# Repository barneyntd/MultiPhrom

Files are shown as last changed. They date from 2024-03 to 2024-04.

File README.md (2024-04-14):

Multiphrom
==========

Multiphrom is a small microcontroller based board designed to emulate serial speech ROMS (phroms) for the BBC microcomputer.
It differs from many similar devices in several ways:
1.  Rather than emulating just one phrom, Multiphrom emulates up to 64;
2.  The contents of the emulated phroms can be updated at any time by inserting a micro-SD card;
3.  Multiphrom attempts to detect other phroms and stops using contended addresses;
4.  Multiphrom plugs into the official cartridge slot in the keyboard (the ashtray), or onto the external rom connector, PL14.

#### Project folders
- **kicad** This holds the schematic and pcb design, as a kicad project;
- **src** This holds the source code, written in C, and a Makefile to build it;
- **docs** This holds documents explaining how to use multiphrom, and the BBC micro speech system;
- **BASIC** This holds several sample programs, written in BBC BASIC.
- **Phroms** This holds some sample phroms for testing.

#### Licence
This project is licensed under creative commons licence [CC BY-NC-SA 4.0](https://creativecommons.org/licenses/by-nc-sa/4.0/).
This means that you are free to use it for any noncommercial purpose, provided you credit the copyright holder, and pass on the same conditions.
If you want to create a commercial product based on Multiphrom, you must obtain a seperate licence from the copyright holder.

The project includes the [sd-reader](http://www.roland-riegel.de/sd-reader/index.html) library by Roland Riegel, which is licenced under GNU LGPL v2.1.

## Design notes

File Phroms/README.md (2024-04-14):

Phroms
======

This folder contains sample phroms in the format used by MultiPhrom.
Put them on a micro-SD card, plug it into Multiphrom, and wait for the LED to go out.

> *I do not own the copyright on some of these files!
I have included them here for testing, but they should not be included in distributions.
If you are the copyright holder, please let me know what you would like me to do about your data*

1. **Ph\_EFR** This is VM71003A, the speaking clock rom.
2. **Ph\_F0R** This is VM61002, the phrom included in the US version of the model B.
3. **Ph\_FEN** This is a phrom created using PHSAVE, containing BASIC files for the \*ROM filing system.
4. **Ph\_FFN** This is CM62024, the Kenneth Kendal phrom included in the BBC speech upgrade.

The filename controls how MultiPhrom treats the files:
* Any filename not of the form "Ph\_hhr" where hh is a hex value between C0 and FF,
and r is N or R, is ignored.
* The two characters hh are the slot number in which the phrom will be installed.
Phrom data is not slot specific, so phroms can be installed in any slot.
* The character r controls whether the data will be bit-reversed. Rom dumps are usually
bit reversed; home created data is usually not.

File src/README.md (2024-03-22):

Building MultiPhrom
===================

This folder contains the source code for MultiPhrom's firmware. In order to build it, you will need:
1.  avr-gcc
2.  [avr-libc](https://github.com/avrdudes/avr-libc)   (if you use the atmega168pb mcu, you may need to edit some of the avr-libc files)
4.  [avrdude](https://github.com/avrdudes/avrdude)
5.  a suitable programmer.

Before building the firmware, you will probably need to edit the Makefile to suit your setup:
1.  You must set AVRDUDE_PROGRAMMER and AVRDUDE_PORT to whatever programmer you are using. See the avrdude documentation for details.
2.  The default microcontroller is an atmega168pb, but it should work with any atmega168 or atmega328 variant. Set MCU accordingly.

The board has a solder jumper marked "program". In order to protect the 3.3v memory chip from the 5v programming level, it is
advisable to desolder this jumper before programming, and resolder it after.

To build the firmware and program the mcu, connect up the programmer and execute the commands:
1.  `make setup`  (this is not needed if the mcu has been used before)
2.  `make clean`
3.  `make all`
4.  If you want to program several boards with the same firmware, you can use `make program`

If you get lots of errors about undefined things, you may need to edit the file `include/avr/io.h` in your avr-libc installation:
1.  After the line `#  include <avr/iom328p.h>` add the lines
     ```
    #elif defined (__AVR_ATmega328PB__)
    #  include <avr/iom328pb.h>
    ```
2.  After the line `#  include <avr/iom168pa.h>` add the lines
     ```
    #elif defined (__AVR_ATmega168PB__)
    #  include <avr/iom168pb.h>
    ```
3.  Make sure the files `include/avr/iom328pb.h` and `include/avr/iom168pb.h` exist

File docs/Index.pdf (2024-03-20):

CM62024 (BBC UK Phrom,

### Kenneth Kendall)

Index | Address | Word
32 | 0250 | (0.125)
33 | 35CA | TEN
34 | 0692 | 2- (TWEN-)
35 | 073F | 3- (THIR-)
36 | 07F7 | 4- (FOR-)
37 | 08B6 | 5- (FIF-)
38 | 0936 | 6- (SIX-)
39 | 09CB | 7- (SEVEN-)
40 | 0A46 | 8- (EIGHT-)
41 | 0AFD | 9- (NIN-)
42 | 3874 | TIME
43 | 2C45 | PLUS
44 | 0530 | THOUSAND (000)
45 | 2321 | MINUS
46 | 2C8B | POINT
47 | 2980 | ON
48 | 0437 | ZERO (0)
49 | 05CA | ONE,WON
50 | 0633 | TWO,TO,TOO
51 | 06D2 | THREE
52 | 0788 | FOUR,FOR,FORE
53 | 0840 | FIVE
54 | 08E9 | SIX
55 | 096E | SEVEN
56 | 0A12 | EIGHT,ATE
57 | 0A71 | NINE
58 | 0272 | (TONE 1)
59 | 02B0 | (TONE 2)
60 | 339A | SMALL
61 | 1F57 | IS
62 | 20FC | LARGE
63 | 3D1A | WHAT
64 | 0D46 | AMOUNT
65 | 0B5D | A
66 | 0065 | B,BEE,BE
67 | 124D | C,SEE,SEA
68 | 14F0 | D
69 | 175A | E
70 | 1A1C | F
71 | 1C6B | G
72 | 1D09 | H
73 | 1DCC | I,EYE
74 | 1FA6 | J,JAY
75 | 2008 | K
76 | 209F | L
77 | 226F | M
78 | 246F | N
79 | 27E5 | O
80 | 2A90 | P,PEA
81 | 2EC8 | Q,QUEUE
82 | 2F1E | R,ARE
83 | 31E1 | S
84 | 3573 | T,TEA,TEE
85 | 3A21 | U,YOU
86 | 3AF7 | V
87 | 3BB8 | W
88 | 3DB5 | X
89 | 3E11 | Y,WHY
90 | 3F9B | Z
91 | 341F | START
92 | 28D9 | OFF
93 | 349F | STOP
94 | 362B | THANK
95 | 21F5 | LINE
96 | 2D64 | POUN-
97 | 0E12 | AND
98 | 10BD | BAD
99 | 1483 | CORRECT
100 | 02E9 | -D
101 | 0300 | -ED
102 | 1AAB | FILE
103 | 1CC9 | GOOD
104 | 04C8 | HUNDRED (00)
105 | 1EBD | IN-
106 | 032B | -ING
107 | 2061 | KEY
108 | 1E3E | ILLEGAL
109 | 2409 | MUST
110 | 263D | NO,KNOW
111 | 29DE | ONLY
112 | 2DCD | PRESS
113 | 2892 | OF
114 | 3051 | RETURN
115 | 0361 | -S
116 | 36DF | THE
117 | 3F3D | YOUR
118 | 3B5C | VERY

VM61002 (BBC USA Phrom,

### American male)

Index | Address | Word
1 | 019E | ZERO
2 | 01EB | FOUR
3 | 0237 | EIGHT
4 | 026A | TWELVE
5 | 02B3 | TWENTY
6 | 02FF | ONE
7 | 0342 | FIVE
8 | 0395 | NINE
9 | 03ED | THIR-
10 | 0425 | HUNDRED
11 | 047C | TWO
12 | 04B3 | SIX
13 | 04E5 | TEN
14 | 051B | FIF-
15 | 0541 | THOUSAND
16 | 05BA | THREE
17 | 0606 | SEVEN
18 | 0650 | ELEVEN
19 | 06B8 | TEEN-
20 | 06EE | B
21 | 0720 | F
22 | 075A | J
23 | 079D | N
24 | 07DD | R
25 | 0809 | V
26 | 085D | ZEE
27 | 0899 | C
28 | 08DB | G
29 | 0919 | K
30 | 095A | O
31 | 0988 | S
32 | 09B8 | W
33 | 0A1E | D
34 | 0A52 | H
35 | 0A8D | L
36 | 0ACC | P
37 | 0B02 | T
38 | 0B3C | X
39 | 0B75 | A
40 | 0BA3 | E
41 | 0BD9 | I
42 | 0C1B | M
43 | 0C5A | Q
44 | 0C8E | U
45 | 0CCC | Y
46 | 0D0E | ALPHA
47 | 0D4F | ECHO
48 | 0D91 | DELTA
49 | 0DE4 | BRAVO
50 | 0E41 | FOXTROT
51 | 0EB0 | CHARLIE
52 | 0F01 | GOLF
53 | 0F39 | HENRY
54 | 0F89 | LIMA
55 | 0FD2 | PAPA
56 | 1014 | TANGO
57 | 106C | XRAY
58 | 10D0 | THE
59 | 10F7 | WATTS
60 | 1146 | METER
61 | 1191 | DANGER
62 | 11E4 | PRESSURE
63 | 1228 | CHANGE
64 | 1291 | MINUS
65 | 12E1 | NOT
66 | 1326 | START
67 | 1371 | LINE
68 | 13C5 | OFF
69 | 13F1 | TIME
70 | 142E | AUTOMATIC
71 | 14AC | WEIGHT
72 | 14FB | SMOKE
73 | 153C | ABORT
74 | 15A6 | CALL
75 | 15E2 | CYCLE
76 | 1630 | DISPLAY
77 | 168B | EQUAL
78 | 16DD | FAST
79 | 172B | ABOUT
80 | 1788 | GO
81 | 17AE | INCH
82 | 17F4 | LOW
83 | 1824 | MOTOR
84 | 1869 | OPEN
85 | 18B2 | PERCENT
86 | 1904 | PROBE
87 | 194E | READY

VM71003A (Time,

### American female)

Index | Address | Word
1 | 0048 | THE
2 | 006A | TIME
3 | 00F7 | IS
4 | 015C | A.M.
5 | 0203 | P.M.
6 | 0283 | OH
7 | 02BF | O-CLOCK
8 | 031D | ONE
9 | 0383 | TWO
10 | 03B6 | THREE
11 | 041E | FOUR
12 | 047B | FIVE
13 | 04F9 | SIX
14 | 052C | SEVEN
15 | 0584 | EIGHT
16 | 05CB | NINE
17 | 063F | TEN
18 | 06A6 | ELEVEN
19 | 0733 | TWELVE
20 | 07AE | THIRTEEN
21 | 084E | FOURTEEN
22 | 08C5 | FIFTEEN
23 | 0958 | SIXTEEN
24 | 09F0 | SEVENTEEN
25 | 0AAB | EIGHTEEN
26 | 0B46 | NINETEEN
27 | 0C08 | TWENTY
28 | 0C71 | THIRTY
29 | 0CDC | FOURTY
30 | 0D47 | FIFTY
31 | 0DA8 | GOOD-
32 | 0DC7 | MORNING
33 | 0E52 | AFTERNOON
34 | 0EF3 | EVENING
35 | 0F6C | (PAUSE)

VM61003 (Weather,

### American male)

Index | Address | Word
- | 0000 | ZERO
- | 004D | ONE
- | 0090 | TWO
- | 00C7 | THREE
- | 0113 | FOUR
- | 015D | FIVE
- | 0180 | SIX
- | 0203 | SEVEN
- | 0261 | EIGHT
- | 02A4 | NINE
- | 0336 | TEN
- | 0389 | ELEVEN
- | 0414 | TWELVE
- | 045D | THIRTEEN
- | 04E6 | FOURTEEN
- | 0584 | FIFTEEN
- | 060B | SIXTEEN
- | 0698 | SEVENTEEN
- | 073B | EIGHTEEN
- | 07AB | NINETEEN
- | 0845 | TWENTY
- | 0891 | THIRTY
- | 08E9 | FOURTY
- | 0956 | FIFTY
- | 09C1 | SIXTY
- | 0A2D | SEVENTY
- | 0AB0 | EIGHTY
- | 0B02 | NINETY
- | 0B6C | HUNDRED
- | 0BC3 | THOUSAND
- | 0C72 | MILLION
- | 0CEC | HALF
- | 0D4F | NEGATIVE
- | 0DE6 | POINT
- | 0E33 | AFFIRMATIVE
- | 0EE7 | TIMES
- | 0F69 | DIVIDED
- | 0FD9 | BY
- | 1047 | HOURS
- | 10AC | PLUS
- | 10F1 | MINUS
- | 116D | EQUALS
- | 11DB | RED
- | 1254 | YELLOW
- | 12A6 | GREEN
- | 1325 | WHITE
- | 136B | THE (EE)
- | 139E | THE (UH)
- | 13BF | ANSWER
- | 142A | IS
- | 1482 | START
- | 14E4 | STOP
- | 153D | READY
- | 157D | TEMPERATURE
- | 1610 | TIME
- | 167B | A.M.
- | 172D | P.M.
- | 17DF | O-CLOCK
- | 1847 | DEGREES
- | 18FE | CELCIUS
- | 19AC | FAHRENHEIT
- | 1A4B | ERROR
- | 1AA7 | MILES
- | 1B2F | PER
- | 1B74 | HOUR
- | 1BDB | MINUTES
- | 1C51 | GUSTING TO
- | 1D06 | DUST
- | 1D5E | EAST
- | 1DC4 | WEST
- | 1E30 | SOUTH
- | 1E91 | NORTH
- | 1EFE | NORTHEAST
- | 1FB7 | NORTHWEST
- | 2061 | SOUTHEAST
- | 210D | SOUTHWEST
- | 21C1 | HAIL
- | 222B | TORNADO
- | 22C2 | WIND
- | 2340 | WEATHER
- | 23BD | SHOWERS
- | 2448 | SLEET
- | 24AF | SMOKE
- | 2520 | STORM
- | 25AC | SNOW
- | 2627 | SAND
- | 26B6 | PELLETS

VM61004 (Military radio,

### American male)

Index | Address | Word
- | 0000 | ALPHA
- | 0064 | BRAVO
- | 00BC | CHARLIE
- | 011E | DELTA
- | 0171 | ECHO
- | 01B3 | FOXTROT
- | 0248 | GOLF
- | 0280 | HOTEL
- | 02F6 | INDIA
- | 0356 | JULIET
- | 03BC | KILO
- | 0409 | LIMA
- | 044C | MIKE
- | 048E | NOVEMBER
- | 052A | OSCAR
- | 0587 | PAPA
- | 05C9 | QUEBEC
- | 0610 | ROMEO
- | 0670 | SIERRA
- | 0706 | TANGO
- | 077D | UNIFORM
- | 07FB | VICTOR
- | 086E | WHISKY
- | 08C7 | XRAY
- | 093B | ZULU
- | 0984 | AFFIRMATIVE
- | 0A38 | NEGATIVE
- | 0ACF | MAYDAY
- | 0B74 | WARNING
- | 0C07 | ICING
- | 0C78 | DANGER
- | 0D0B | EMERGENCY
- | 0DD2 | ROGER
- | 0E50 | HERTZ
- | 0E8D | (PAUSE)
- | 0E96 | SECURITY
- | 0F13 | TARGET
- | 0F6E | VECTORS
- | 0FE6 | LIGHT
- | 103D | FRONT
- | 1098 | WAY
- | 10DA | GLIDE
- | 115E | OPEN
- | 11C2 | LIGHTS
- | 1221 | ON
- | 1287 | GUN DISH
- | 130A | ARDNAV
- | 13B9 | SELECT
- | 1420 | FILED
- | 14A5 | MIG
- | 1511 | ALERT
- | 1579 | ZONE
- | 15FD | TERMINAL
- | 167E | CANCEL
- | 16EB | RADIOS
- | 178E | SPEED
- | 1800 | KNOTS
- | 1868 | EXPECT
- | 18D6 | ACTION
- | 193C | RADIO
- | 19AA | POWER
- | 1A07 | PATH
- | 1A5F | INFORMATION
- | 1B09 | TRUE
- | 1B52 | PRESSURE
- | 1BBF | CHECK
- | 1BF6 | DECREASE
- | 1C63 | ADVISE
- | 1CED | YOU
- | 1D27 | HALF
- | 1D7E | ERROR
- | 1DDA | CALL
- | 1E31 | WRONG
- | 1E91 | NO
- | 1EEA | IMMEDIATELY
- | 1FA3 | FINAL
- | 200F | PLEASE
- | 205A | START
- | 20B6 | COURSE
- | 2102 | RADAR
- | 2181 | PLAN
- | 21EE | TARGET
- | 225B | WINDOWS
- | 22F3 | WATCH
- | 2336 | USE (S)
- | 2381 | TURN
- | 23CE | TRAFFIC

VM61005 (Aviation,

### American male)

Index | Address | Word
- | 0000 | A.P.U.
- | 00CC | F.S.S.
- | 01A8 | I.L.S.
- | 0276 | I.F.R.
- | 034B | V.F.R.
- | 0420 | V.H.E.
- | 052F | LANDING GEAR
- | 060C | LEVEL OFF
- | 06CE | UNDERCARRIAGE
- | 0791 | SPOILERS
- | 083F | AIR BRAKES
- | 08DB | AERIAL
- | 0960 | ENGINE
- | 09E4 | FLAMEOUT
- | 0A70 | FLAP LOAD
- | 0B36 | INBOUND
- | 0C08 | IGNITE
- | 0C7A | NO TURN
- | 0D47 | FLAPS
- | 0DB3 | EVACUATION
- | 0E8F | DOORS
- | 0F13 | CABIN
- | 0F7F | ARRIVAL
- | 1018 | AKNOWLEDGE
- | 10C2 | RAISE
- | 1156 | LIST
- | 11C2 | APPROACH
- | 123F | DEPARTURE
- | 12C5 | CLEARANCE DELIVERY
- | 13BB | FUEL
- | 142B | IDLE
- | 1495 | INCREASE
- | 150D | UP
- | 154E | TAXI
- | 15BB | EZZ
- | 15F6 | CONVERGING
- | 1690 | ABOVE
- | 16F6 | BRAKE
- | 174E | CALM
- | 17C6 | BRAKING
- | 1837 | CALL
- | 189E | CROSSWIND
- | 1938 | CRYSTALS
- | 19A6 | CYLINDER
- | 1A32 | CYCLE
- | 1A99 | DOWN
- | 1AF3 | GROUND
- | 1B4B | FULL
- | 1B9A | NEW
- | 1C19 | LEG
- | 1C8B | MAINTAIN
- | 1D37 | LANDING
- | 1DC2 | LEAN
- | 1E2E | SET
- | 1E75 | SHORT
- | 1ECB | WAKE
- | 1F28 | (PAUSE)
- | 1F31 | ATUS
- | 1F86 | NOTEM
- | 1FF9 | R.V.R.s
- | 20ED | SQUAWKING
- | 2161 | MAGNETOS
- | 220E | STABALISER
- | 22C7 | TACAN
- | 2344 | SELCAL
- | 23DF | VORTEC
- | 247F | V.O.R.
- | 256A | MARKER
- | 25DD | HEADING
- | 263E | E.T.A.
- | 26F4 | DOWNWIND
- | 2789 | CEILING
- | 27F2 | MIDPOINT
- | 288B | SIGMET
- | 2906 | ROLLOUT
- | 29A4 | PROPS
- | 29FD | AIRCRAFT
- | 2E89 | ALTIMETER
- | 2B20 | RUNWAY
- | 2BAB | AUTOPILOT
- | 2C47 | LOCALISER
- | 2CFE | COWL
- | 2D5D | IN FLIGHT
- | 2DF6 | OVER SPEED
- | 2EA7 | DEPARTURE
- | 2F3B | LAUNCH

119 | 3D6E | WHICH
120 | 276A | NUMBER
121 | 3EFC | YES
122 | 03DC | -Z
123 | 1B1E | FIRST
124 | 2A48 | OR
125 | 2195 | LAST
126 | 269D | NOT,KNOT
127 | 0250 | (0.125)
128 | 025F | (0.25)
129 | 0272 | (TONE 1)
130 | 02B0 | (TONE 2)
131 | 02E9 | -D
132 | 0300 | -ED
133 | 032B | -ING
134 | 0361 | -S
135 | 0384 | -TEE
136 | 03DC | -TH
137 | 03F3 | -T
138 | 0415 | -
139 | 0437 | ZERO (0)
140 | 04C8 | HUNDRED (00)
141 | 0530 | THOUSAND (000)
142 | 05CA | ONE,WON
143 | 0633 | TWO,TO,TOO
144 | 0692 | 2- (TWEN-)
145 | 06D2 | THREE
146 | 073F | 3- (THIR-)
147 | 0788 | FOUR,FOR,FORE
148 | 07F7 | 4- (FOR-)
149 | 0840 | FIVE
150 | 08B6 | 5- (FIF-)
151 | 08E9 | SIX
152 | 0936 | 6- (SIX-)
153 | 096E | SEVEN
154 | 09CB | 7- (SEVEN-)
155 | 0A12 | EIGHT,ATE
156 | 0A46 | 8- (EIGHT-)
157 | 0A71 | NINE
158 | 0AFD | 9- (NIN-)
159 | 0B5D | A
160 | 0BB6 | ACORN
161 | 0C4B | AFTER
162 | 0CB3 | AGAIN
163 | 0D46 | AMOUNT
164 | 0DBD | AN
165 | 0E12 | AND
166 | 0E8E | ANOTHER
167 | 0EFD | ANSWER
168 | 0F72 | ANY
169 | 0FCF | AVAILABLE
170 | 0065 | B,BEE,BE
171 | 10BD | BAD
172 | 013B | BETWEEN
173 | 01B1 | BOTH
174 | 01F8 | BUTTON
175 | 124D | C,SEE,SEA
176 | 12B1 | CASSETTE
177 | 1326 | CHARACTER
178 | 139F | COMPLETE
179 | 140B | COMPUTER
180 | 1483 | CORRECT
181 | 14F0 | D
182 | 153B | DATA
183 | 159F | DATE
184 | 15E6 | DO
185 | 162A | DOLLAR
186 | 167E | DONT
187 | 16D7 | DOWN
188 | 175A | E
189 | 178B | EACH
190 | 17D6 | ELEVEN
191 | 1852 | ENGAGED
192 | 18FA | ENTER
193 | 195C | ERROR
194 | 19AA | ESCAPE
195 | 1A1C | F
196 | 1A5D | FEW
197 | 1AAB | FILE
198 | 1B1E | FIRST
199 | 1896 | FOUND
200 | 1C11 | FROM
201 | 1C6B | G
202 | 1CC9 | GOOD
203 | 1D09 | H
204 | 1D60 | HAVE
205 | 1DCC | I,EYE
206 | 1E3E | ILLEGAL
207 | 1EBD | IN-
Index | Address | Word
88 | 198E | SET
89 | 19CC | SPEED
90 | 1A16 | UNDER
91 | 1A6A | OPERATOR
92 | 1AE7 | INDIA
93 | 1B3B | MIKE
94 | 1B7D | QUEBEC
95 | 1BC4 | UNIFORM
96 | 1C42 | YANKEE
97 | 1CA5 | AMPS
98 | 1CE0 | MEGA
99 | 1D2A | PICO
100 | 1D80 | FIRE
101 | 1DD3 | POWER
102 | 1E21 | COMPLETE
103 | 1E8B | REPAIR
104 | 1EEC | TEMPERATURE
105 | 1F41 | STOP
106 | 1F70 | MACHINE
107 | 1FCE | ON
108 | 200A | CONTROL
109 | 2071 | ELECTRICIAN
110 | 20E2 | AT
111 | 2111 | RED
112 | 2160 | ALL
113 | 2197 | CANCEL
114 | 21DD | PHASE
115 | 221F | NOR
116 | 226C | EXIT
117 | 22BA | FLOW
118 | 22FB | GAUGE
119 | 234A | GREEN
120 | 23B9 | INSPECTOR
121 | 242A | MANUAL
122 | 24A1 | MOVE
123 | 24FC | OVER
124 | 2547 | PLUS
125 | 2583 | PULL
126 | 25BD | REPEAT
127 | 2621 | SHUT
128 | 2658 | TEST
129 | 2696 | VOLTS
130 | 26D3 | GALLONS
131 | 2737 | JULIET
132 | 279D | NOVEMBER
133 | 2814 | ROMEO
134 | 2874 | VICTOR
135 | 28CB | ZULU
136 | 2914 | HERTZ
137 | 2948 | MICRO
138 | 299C | OHMS
139 | 29F0 | AREA
140 | 2A43 | CIRCUIT
141 | 2A9E | CONNECT
142 | 2AEB | SECONDS
143 | 2B55 | UNIT
144 | 2BB2 | TIMER
145 | 2BFD | UP
146 | 2C28 | IS
147 | 2C5F | ALERT
148 | 2CBA | ADJUST
149 | 2D1B | BETWEEN
150 | 2D77 | MINUTES
151 | 2DBD | BUTTON
152 | 2E0B | CLOCK
153 | 2E49 | DEVICE
154 | 2E97 | EAST
155 | 2ED8 | FAIL
156 | 2F1D | FREQUENCY
157 | 2F8B | GATE
158 | 2FD4 | HIGH
159 | 300A | INTRUDER
160 | 307D | MEASURE
161 | 30CE | NORTH
162 | 3121 | PASS
163 | 3172 | POSITION
164 | 31D1 | PUSH
165 | 3201 | WRITE
166 | 324A | SLOW
167 | 3292 | TOOL
168 | 32D1 | WEST
169 | 3324 | KILO
170 | 3373 | OSCAR
171 | 33C6 | SIERRA
172 | 341D | WHISKY
173 | 3476 | AND
174 | 34CD | FARAD
175 | 351D | MILLI
176 | 3556 | CAUTION
Index | Address | Word
- | 2718 | RAIN
- | 2788 | ICE
- | 27E6 | FEET
- | 282E | FOG
- | 289D | HEAVY
- | 28DF | LAND
- | 294F | IN
- | 298F | ON
- | 29CB | VARIABLE
- | 2A6A | OBSCURED
- | 2B09 | BROKEN
- | 2B68 | ALOFT
- | 2BDF | CEILING
- | 2C48 | PARTIALLY
- | 2CC2 | VISIBILITY
- | 2D7A | DRIZZLE
- | 2DDD | INDICATED
- | 2E74 | SEVERE
- | 2ED7 | MODERATE
- | 2F59 | GREENWICH
- | 2FCA | MEAN
- | 3043 | MIST
- | 30C0 | ESTIMATED
- | 314D | DECREASING
- | 31F0 | MOVING
- | 325C | PRESSURE
- | 32C9 | ALTERNATE
- | 334F | CLEAR
- | 33AA | CURRENT
- | 33F4 | FLOWING
- | 3470 | AT
- | 34AA | TURBULENCE
- | 353B | THINLY
- | 3599 | INCREASING
- | 3634 | MORE THAN
- | 36DB | LESS THAN
- | 3763 | FREEZING
- | 37EA | AIR
- | 382A | BELOW
- | 38A6 | AND
- | 38ED | FOR
- | 3927 | HAZE
- | 39A5 | HIGH
- | 3A0D | SCATTERED
- | 3A8E | INCREASING TO
- | 3B6A | IN
- | 3BB7 | LOW (SHORT)
- | 3BE7 | OF
- | 3C2E | (PAUSE)
- | 3C37 | THUNDERSTORMS
- | 3CFB | OVERCAST
- | 3DC7 | UNLIMITED
- | 3E7B | LOW (LONG)
- | 3EF4 | PERCENT
- | 3F46 | OVER
Index | Address | Word
- | 2435 | TECH
- | 248A | SLOW
- | 24F9 | RELEASE
- | 256D | KEY
- | 25A8 | IGNITION
- | 2639 | DEGREE
- | 26A4 | GRAIN
- | 26F9 | REPAIR
- | 277C | CANCEL
- | 2806 | VERIFY
- | 28A0 | READY
- | 28FA | USE (Z)
- | 2976 | OUT
- | 29BF | OTHER
- | 2A25 | OIL
- | 2A78 | OFF
- | 2AC6 | MIRROR
- | 2B26 | RATE
- | 2B93 | MIXTURE
- | 2C16 | MUCH
- | 2C6E | RATE
- | 2CD0 | IS
- | 2D28 | CAUTION
- | 2D97 | BELOW
- | 2E13 | CYLINDER
- | 2E90 | CONTACT
- | 2F0A | AND
- | 2F51 | FUEL
- | 2FA8 | FOR
- | 2FE2 | SEQUENCE
- | 3068 | SIDE
- | 30C3 | SLOW
- | 3119 | TO
- | 3148 | RICH
- | 31B6 | PUMPS
- | 320C | LEVEL
- | 3273 | LOWER
- | 32E5 | REAR
- | 3364 | HOLD
- | 33C9 | LONG
- | 3435 | LEVEL
- | 34AE | LEFT
- | 350F | RIGHT
- | 356F | OPEN
- | 35C9 | STRAY
- | 3659 | CLOSED
- | 36E2 | EVACUATE
- | 379A | FAILURE
- | 3807 | SERVICE
- | 3881 | ABORT
- | 3902 | IDENTIFY
- | 3999 | TOO LOW
- | 3A2F | CENTRE
- | 3AA9 | AREA
- | 3B09 | BASE
- | 3B45 | CONTROL
- | 3BBB | MEASURED
- | 3C41 | THE (EE)
- | 3C74 | THE (UH)
- | 3C95 | VACUUM
- | 3D13 | ABEAM
- | 3D95 | (PAUSE)
Index | Address | Word
- | 2F9F | TOWER
- | 3006 | FLIGHT WATCH
- | 30AC | STALL
- | 312B | TOUCHDOWN
- | 31BF | SQUAWK
- | 321D | ELEVATION
- | 32D0 | CLIMB
- | 3342 | BANK
- | 33A3 | ACCELERATED
- | 344E | TRIM
- | 34A0 | UNICOM
- | 3546 | SLOPE
- | 3595 | NINER
- | 361E | GALLEY
- | 3675 | FREEDOM
- | 36F0 | FLIGHT
- | 3749 | DEGREE
- | 37B4 | AIRPORT
- | 3820 | AIR SPEED
- | 38AE | CLEARENCE
- | 3920 | ALTITUDE
- | 39BB | RADIO
- | 3A53 | REMARK
- | 3AEA | REFUELLING
- | 3B9C | OUTER
- | 3BF9 | MIDDLE
- | 3C5F | INNER
- | 3CAC | INSTRUMENTS
- | 3D55 | FLIGHT
- | 3DB0 | APPROACHES
- | 3E55 | GEAR
- | 3EA8 | BOOST
- | 3EE7 | TELEPHONE
Index | Address | Word

208 | 1EFC | INPUT
209 | 1F57 | IS
210 | 1FA6 | J,JAY
211 | 2008 | K
212 | 2061 | KEY
213 | 209F | L
214 | 20FC | LARGE
215 | 2195 | LAST
216 | 21F5 | LINE
217 | 226F | M
218 | 22CD | MANY
219 | 2321 | MINUS
220 | 239D | MORE
221 | 2409 | MUST
222 | 246F | N
223 | 24C9 | NAME
224 | 2544 | NEGATIVE
225 | 25DE | NEW
226 | 263D | NO,KNOW
227 | 269D | NOT,KNOT
228 | 26F7 | NOW
229 | 276A | NUMBER
230 | 27E5 | O
231 | 282D | O'CLOCK
232 | 2892 | OF
233 | 28D9 | OFF
234 | 2923 | OLD
235 | 2980 | ON
236 | 29DE | ONLY
237 | 2A48 | OR
238 | 2A90 | P,PEA
239 | 2AC7 | PARAMETER
240 | 2B58 | PENCE
241 | 2BBA | PLEASE
242 | 2C45 | PLUS
243 | 2C8B | POINT
244 | 2CE6 | POSITIVE
245 | 2D64 | POUN-
246 | 2DCD | PRESS
247 | 2E3F | PROGRAM
248 | 2EC8 | Q,QUEUE
249 | 2F1E | R,ARE
250 | 2F59 | RED
251 | 2FD1 | RESET
252 | 3051 | RETURN
253 | 30E7 | RUN
254 | 3153 | RUNNING
255 | 31E1 | S
256 | 3231 | SAME
257 | 329A | SCORE
258 | 3320 | SECOND
259 | 339A | SMALL
260 | 341F | START
261 | 349F | STOP
262 | 34FB | SWITCH
263 | 3573 | T,TEA,TEE
264 | 35CA | TEN
265 | 362B | THANK
266 | 3684 | THAT
267 | 36DF | THE
268 | 3724 | THEN
269 | 377E | THIRD
270 | 3808 | THIS
271 | 3874 | TIME
272 | 3800 | TRY
273 | 3953 | TWELVE
274 | 39D2 | TYPE
275 | 3A21 | U,YOU
276 | 3A91 | UH
277 | 3AC0 | UP
278 | 3AF7 | V
279 | 3B5C | VERY
280 | 3BB8 | W
281 | 3C1D | WANT
282 | 3C6C | WAS
283 | 3CC2 | WERE
284 | 3D1A | WHAT
285 | 3D6E | WHICH
286 | 3DB5 | X
287 | 3E11 | Y,WHY
288 | 3E86 | YEAR
289 | 3EFC | YES
290 | 3F3D | YOUR
291 | 3F9B | Z
Index | Address | Word
177 | 35B1 | LIGHT
178 | 3601 | CHECK
179 | 3635 | DEGREES
180 | 36CB | SERVICE
181 | 3721 | SWITCH
182 | 376E | VALVE
183 | 37CC | VAL
184 | 3820 | NUMBER
185 | 3880 | OUT
186 | 38B5 | POINT
187 | 3904 | BREAK
188 | 3948 | HOURS
189 | 39AD | CALIBRATE
190 | 3A21 | CRANE
191 | 3A75 | DIRECTION
192 | 3AE3 | ENTER
193 | 3B17 | FEET
194 | 3B56 | FROM
195 | 3B86 | GAP
196 | 3BC8 | HOLD
197 | 3C22 | LEFT
198 | 3C61 | MILL
199 | 3C9C | OF
200 | 3CC5 | PAST
201 | 3D11 | PRESS
202 | 3D54 | RANGE
203 | 3DB2 | SAFE
204 | 3DF2 | SOUTH
205 | 3E48 | TURN
206 | 3E8B | YELLOW
Index | Address | Word

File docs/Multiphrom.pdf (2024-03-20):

# Multiphrom

Multiphrom is a serial rom emulator for use with the TMS5220 speech chip, designed to get the most possible out of the BBC micro speech system. This document summarises what I have learnt about the speech system, and describes how to use Multiphrom.

## Phrom Numbers

The Speech System User Guide implies that the system can access up to 16 phroms, numbered 0–F, each holding 16Ki of data. In fact, both the TMS5220 and OS1.2 use a 20 bit address, accessing up to 64 phroms; the limitation is the TMS6100 serial rom, which ignores the top two bits. Multiphrom uses all 20 bits, emulating 64 phroms numbered -64 to -1 or &FFC0 to &FFFF. If you use a genuine TMS6100 chip it will appear four times, as &Cn, &Dn, &En, and &Fn.

## Phrom Formats

There are three data formats used in TMS6100 roms for the Beeb, and rom dumps are found in both bit orders. I will refer to the order used in the Speech System User Guide (which puts the Acorn copyright message in the Kenneth Kendal rom into Ascii) as Normal order, and the opposite as Reversed order, and I will describe all data in Normal order. Note that most pointers are reversed, but most other data is not.

### Acorn Format

This is the format described in the Speech System User Guide, and used in the Kenneth Kendal rom (CM62024). The rom starts with a 64 byte header which is completely ignored by the speech system (though used by the *ROM filing system), then continues exactly as Indexed Format. In fact, if you use word numbers less than 32, OS1.2 will interpret the header as part of the index and produce random noise.

### Indexed Format

This is the format used in the US phrom (VM61002), and the speaking clock phrom (VM71003A). In practice, this is the format assumed by OS1.2 for speech data, since it is identical to Acorn format for word numbers greater than 31. To speak words in this format, use

### SOUND ph, wn, 0, 0

where ph is the phrom number (&FFC0–&FFFF) and wn the word number.

Address | Data
0 | 00
1 | word count reversed (not checked by OS1.2)
2 | word 1 address low byte reversed
3 | word 1 address high byte reversed
⋮
2n | word n address low byte reversed
2n+1 | word n address high byte reversed

The rest of the phrom is speech data exactly like Unformatted phroms.

### Unformatted Phroms

This is the format used by the other three easily available phroms (VM61003, VM61004, VM61005) and is just raw data, starting at address zero, one word starting at the first byte after another ends. To speak words in this format, use

### SOUND ph-&40, wadd, 0, 0

where ph-&40 is the phrom number minus 64 (&FF80–&FFBF) and wadd the address of the start of the word (relative to the start of the phrom).
The data is a sequence of frames which can be 4, 11, 19, or 50 bits long, packed into bytes from high bit to low bit, and byte aligned only at word boundaries. Each frame is a sequence of up to twelve parameters, each of 3,4,5 or 6 bits, which index standard tables. I believe each parameter is in Normal order, but I haven’t checked this.

## Loading Phroms into Multiphrom

You can load any phrom into any slot in multiphrom. Create a file containing the raw binary data at the root level of a micro-SD card, with the name Ph_XXN if the bytes are in normal order, or Ph_XXR if they are reversed, where XX is the slot you want to put it in (C0-FF). Insert the card into multiphrom and the led will light; when it goes out you can remove the card and use the speech system. Each slot takes about 5 seconds to load, so it is a good idea to delete or rename phrom files after loading.
If you have a genuine TMS6100 installed, it will take up four slots. Multiphrom should detect it and disable itself for those slots, but I haven’t been able to test this properly, as I don’t have a TMS6100. You can still load data into those slots, but not use it until you remove the TMS6100.

## Using the *ROM Filing System

In OS1.2, the *ROM FS only searches slots &F0–&FF, so capacity is limited to 256KiB including overheads. It would be a simple patch (I believe only one byte) to allow all 64 slots for 1MiB storage; if any original cartridges exist they would then be repeated four times in the catalogue, which doesn’t seem much of a downside. The format is as described in the New Advanced User Guide, all in normal order, with a header as described in the Speech System Users Guide with pointers in reversed order. I have written a BASIC program to generate appropriate phrom files, but files running over more than one slot should be considered beta, as there is no good documentation, and I haven’t had time to test it thoroughly.

## The Board, V2.0

The board contains an Atmega 168pb micro-controller, an AT25SF081 flash rom, a micro-SD card socket, and various components to connect them together. It is designed to plug into the cartridge socket to the left of the keyboard (the “ashtray”) on a BBC micro. If you don’t have a socket fitted in your Beeb, I recommend buying a 30 pin edge connector (Amp 5530843-2) and pulling out all the contacts on the left hand side, and the third, fourth and fifth from the top on the right, then put a key in the third position. This can be done with fine nosed pliers, and the socket will then solder to the keyboard PCB. WARNING: you may need fix PCB errors on either the main board or the keyboard; check the instructions in the BBC service manual for details. Failure to fix these errors may fry the board.

The board can also be plugged into PL14 (the second keyboard connector) on the Beeb either with a female header connector or a cable but WARNING: the pins are not quite in the same order. The -5V line is shifted from one end to the other, and connecting this wrong may fry the board. The simplest solution is to connect only the other nine lines, since -5V is not used by the board. If you decide to do this, do check the schematics carefully!

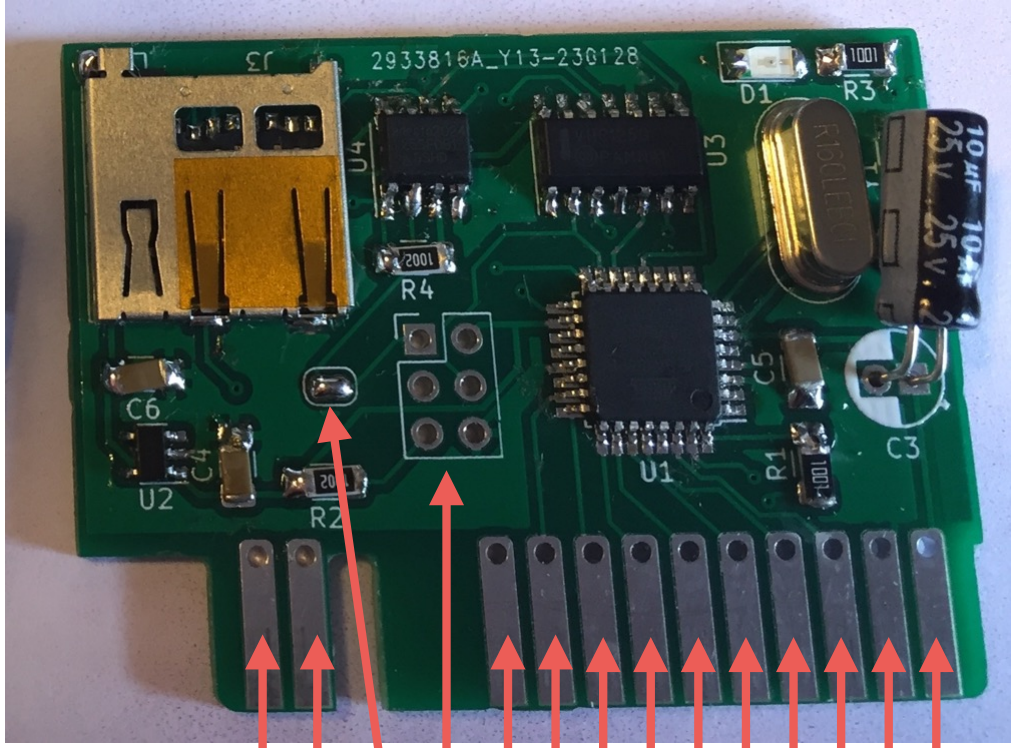
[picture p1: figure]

After testing, the flash rom should contain the UK speech phrom in slot FF, the US speech phrom in slot F0, the US speaking clock phrom in slot EF, and some BASIC programs (in *ROM format) in slot FE.

If you ever want to update the firmware, first desolder the programming jumper with desoldering braid, to protect the 3.3V chips from the 5V programming signals. The programming connector is a standard (Arduino style) ISP6 connector, and any Atmel-compatible programmer should work. After programming, remember to resolder the programming jumper.

## Questions for Beta Testers

- Does it work reliably? Can you use it in all the expected ways?
- Can you find interesting new ways to use it? Are there straightforward improvements I could make to make it more useful?
- How easy is it to install in a Beeb? Which connection system works best?
- (If you have a genuine TMS6100) Does the automatic detection of genuine phroms work? You can test this with SOUND -17 for the UK phrom, or -32 for the US phrom: if the detection works, this should produce the installed phrom, just like SOUND -1 or -16. If it doesn’t, I recommend
removing the TMS6100 when using Multiphrom. NC | NC | Programming jumper | Programming connector | -5V ⁽NC⁾
A1

A2

A4

A8

RCLCK
M0

M1

0V

+5V

## The Programs

I’ve included some simple programs which use the speech rom, in case you find them useful. These are installed in slot FE (using PHSAVE) so you can load them using *ROM. Feel free to use or adapt them in any way you like.

### PHDUMP

PHDUMP generates a hex dump of the contents of any phrom slot. Just input the slot number in hex, and it will print out the contents, formatted for 80 column modes. For 40 column modes, change the 16 in line 200 to 8 (or however many bytes per line you prefer).

input slot number, and ensure it’s meaningful:
10 PRINT"Input slot number (C0-FF)"; 20 INPUT SN$
30 SN=EVAL("&"+SN$) AND &3F
100 @%=4

set bottom twelve bits of speech address to zero: 110 *FX 159,0,64
120 *FX 159,0,64
130 *FX 159,0,64

set top six bits of address to slot, and next two to zero:
140 A%=159:X%=0:Y%=64+SN*4 MOD 16:R%=USR(&FFF4) 150 A%=159:X%=0:Y%=64+SN DIV 4:R%=USR(&FFF4)

loop through entire phrom slot:
160 FOR I%=0 TO &3FFF

tell TMS5220 to read byte:
170 *FX 159,0,16

read byte from phrom:
180 A%=158:R%=USR(&FFF4)
190 Y%=((R% DIV &10000)-1) AND &FF

print newline & address every 16 bytes, then read byte:
200 IF I% MOD 16 = 0 THEN PRINT:PRINT~I%," ",; 210 PRINT ~Y%,;

loop & end
220 NEXT
230 END

### PHLIST

PHLIST searches through all installed phroms looking for those in Acorn format, recognised by the copyright message which starts at byte 2. This is useful to find which slots contain *ROM files.

loop through the 64 slots:
100 FOR PN%=0 TO 63

set the bottom 14 address bits to &0002 and the top six to the slot number: 110 *FX 159,0,66
120 *FX 159,0,64

130 *FX 159,0,64
140 A%=159:X%=0:Y%=64+PN%*4 MOD 16:CALL(&FFF4)
150 A%=159:X%=0:Y%=64+PN% DIV 4:CALL(&FFF4)

if the next three characters are not “(C)” go on to the next slot:
160 IF FNREADBYTE <> &28 OR FNREADBYTE <> &43 OR FNREADBYTE <> &29 THEN NEXT:END

read the copyright and title strings, and print them out:
170 C$="(C)"+FNREADSTRING
180 T$=FNREADSTRING
190 PRINT ~PN%+&C0;": ";T$;" “;C$

go on to next slot:
200 NEXT:END

function to read a byte at the current address: 210 DEF FNREADBYTE
220 *FX 159,0,16
230 A%=158:R%=USR(&FFF4)
240 = ((R% DIV &10000)-1) AND &FF

function to read a 0-terminated string at the current address: 250 DEF FNREADSTRING
260 R$=""
270 REPEAT:C=FNREADBYTE
280 IF C=0 THEN UNTIL TRUE: =R$ 290 R$=R$+CHR$(C)
300 UNTIL FALSE

### PHINDEX

PHINDEX searches through an unindexed phrom to find the start address of words. You need the address of the first word; it then scans through, assuming each word immediately follows the last. This technique allowed me to generate indexes of all the readily available TI roms.
Input the slot number (in hex) of the phrom you want to index, then the start address (in hex) of the first word (usually 0); it will then print the address and speak the word, before prompting “More?”. You can press return to continue the search, type a new address, or type N to stop.

input slot number & start address, and make meaningful:
100 INPUT"Slot number (C0-FF)",SN$
110 SN=EVAL("&"+SN$) AND &3F
120 INPUT"Start address (Hex)",SA$
130 SA=EVAL("&"+SA$) MOD &4000

keep track of how many bits are read:
135 BIT%=0
140 REPEAT
150 PRINT "Trying “;~SA

speak the next word (if it is one) & confirm to continue the search:
160 SOUND&FF80+SN,SA,0,0
170 INPUT "More",Q$:IF LEFT$(Q$,1)="N" THEN END
175 IF Q$<>"" THEN SA=EVAL("&"+Q$) MOD&4000:UNTIL FALSE set the 20-bit speech address:
180 A%=159:X%=0:Y%=&40+(SA AND &0F):CALL(&FFF4)
190 A%=159:X%=0:Y%=&40+(SA DIV &10 AND &0F):CALL(&FFF4)
200 A%=159:X%=0:Y%=&40+(SA DIV &100 AND &0F):CALL(&FFF4)
210 A%=159:X%=0:Y%=&40+(SN*4+SA DIV &1000 AND &0F):CALL(&FFF4) 220 A%=159:X%=0:Y%=&40+SN DIV 4:CALL(&FFF4)

loop through the word just spoken:
240 REPEAT

energy is four bits; get more if necessary:
250 IF BIT%<4 THEN PROCNextByte
260 BIT%=BIT%-4:Energy = BYTE% DIV 2^BIT%:BYTE% = BYTE% MOD 2^BIT%

energy 0 means pause, no other data needed:
270 IF Energy=0 THEN UNTIL FALSE

energy 15 means end of word:
280 IF Energy=15 THEN UNTIL TRUE:SA=SA+1:UNTIL FALSE

repeat is one bit, pitch is six bits; if repeat, no more is needed:
290 IF BIT%<1 THEN PROCNextByte
300 BIT%=BIT%-1:Repeat = BYTE% DIV 2^BIT%:BYTE% = BYTE% MOD 2^BIT% 310 IF BIT%<6 THEN PROCNextByte
320 BIT%=BIT%-6:Pitch = BYTE% DIV 2^BIT%:BYTE% = BYTE% MOD 2^BIT% 330 IF Repeat=1 THEN UNTIL FALSE

K1 to K4 are 18 bits total; if pitch is 0 no more is needed:
340 PROCNextByte:PROCNextByte:IF BIT%<18 THEN PROCNextByte
350 BIT%=BIT%-18:K1234 = BYTE% DIV 2^BIT%:BYTE% = BYTE% MOD 2^BIT% 360 IF Pitch=0 THEN UNTIL FALSE

K5 to K10 are 21 bits total:
370 PROCNextByte:PROCNextByte:IF BIT%<21 THEN PROCNextByte
380 BIT%=BIT%-21:K5to10 = BYTE% DIV 2^BIT%:BYTE% = BYTE% MOD 2^BIT%

loop & end:
390 UNTIL FALSE
990 END

read the next byte from the speech processor:
1000 DEF PROCNextByte
1010 *FX 159,0,16
1020 A%=158:R%=USR(&FFF4):B%=((R% DIV &10000)-1) AND &FF 1030 BYTE%=BYTE%*&100+B%:BIT%=BIT%+8
1035 SA=SA+1
1040 ENDPROC

### PHSAVE

PHSAVE creates a phrom file in *ROM format, which is useful to store programs which you can then access without any sideways-rom based filing system. The file is saved in the current filing system, so you need to use some other method to copy it to the root of a micro-SD card before loading it into Multiphrom.

OS1.2 only reads files from slots F0–FF, so it will warn you if you use slots C0–EF. The slot is only used to generate the filename, so you can move to a different slot simply by renaming the file. At the prompt, enter a filename to be read from the current filesystem and added to the rom, or a *command, which can be used to change directory (I’m not sure if changing filesystem will work), or #title, which creates an empty file to use as a catalog separator. When you have done all the files you want, press return at the prompt to complete the phrom file. This version does support files which run over into the next phrom (and changes the filename accordingly), but OS 1.2 gives Block? errors when you *CAT them, unless you turn on *OPT 1,2.

reserve space for OSFILE & OSGBPB operations, and define machine code routines:
1000 DIM BUFF% 260:DIM CTRL% 18:X%=CTRL% AND &FF:Y%=CTRL% DIV &100 1010 PROCCODE(BUFF%)

input slot number & ensure it’s ok:
1020 REPEAT
1030 PRINT "Enter Phrom slot number (C0-FF)";:INPUT PHFN$ 1040 PHFN = EVAL("&"+PHFN$)
1050 UNTIL PHFN >= &C0 AND PHFN <= &FF
1060 IF PHFN < &F0 THEN PRINT "Warning: OS 1.2 only reads files from slots F0 - FF”

open the file for saving the created phrom:
1070 PROCOPEN

loop for each file saved:
1080 REPEAT
1090 PRINT "Slot " STR$~PHFN ", " &3FFF-EXT#(PHFILE) " bytes free." 1100 PRINT "Enter filename to save in Phrom, or *command, or #title,":PRINT "or RETURN to finish";
1110 INPUT SFN$

if blank, end; if * pass to OSCLI; if # create empty file:
1120 IF SFN$ = "" THEN UNTIL TRUE:PROCCLOSE:END
1130 IF LEFT$(SFN$,1) = "*" THEN OSCLI MID$(SFN$,2):UNTIL FALSE 1140 IF LEFT$(SFN$,1)="#"THEN PROCTITLE(MID$(SFN$,2)):UNTIL FALSE

call OSFILE to read file info:
1150 !CTRL%=BUFF%:$BUFF%=SFN$
1160 A%=5:R%=USR(&FFDD)
1170 IF (R% AND &FF) <> 1 THEN PRINT "File not found.":UNTIL FALSE

L% is the length of the file, BLKS% is the number of 256-byte blocks, LA% is the load address, EA% the execution address, AT% the file attributes, SSFN$ the filename simplified for *ROM: 1180 L%=CTRL%!10:BLKS%=(L%-1) DIV 256 +1
1190 LA%=CTRL%!2:EA%=CTRL%!6:AT%=CTRL%?14
1200 SSFN$=SFN$:REPEAT:SSFN$=MID$(SSFN$,INSTR(SSFN$,".")+1):UNTIL INSTR(SSFN$,".")=0
1210 SSFN$=LEFT$(SSFN$,10):N%=LEN(SSFN$)

calculate the address of the next file (or end of rom marker) in NXT%:
1220 NXT%=FNNXT(0)

open the file to be saved, and loop through the blocks:
1230 SFILE=OPENIN(SFN$)
1240 FOR I%=1 TO BLKS%

if we’ve reached the end of the rom, close the rom file and open a new one, recalculating the address of the next file:
1250 FLAG% = (PTR#PHFILE = NXT%):IF FLAG% THEN PROCCLOSE: PHFN=PHFN+1: PROCOPEN: NXT%=FNNXT(I%-1)

if this is the first or last block of a file, or first block of a rom, write a full header, otherwise &23: 1260 IF FLAG% OR I%=1 OR I%=BLKS% THEN PROCHEADER(I%=BLKS%,EOF#(SFILE),I%-1) ELSE BPUT#PHFILE,&23

read a block from the input file, calculate the CRC, and write both to the output file
1270 ?CTRL%=SFILE:CTRL%!1=BUFF%:CTRL%!5=256
1280 A%=4:R%=USR(&FFD1)
1290 BL%=CTRL%!1-BUFF%:!(CTRL%!1)=FNCRC(BL%)
1300 ?CTRL%=PHFILE:CTRL%!1=BUFF%:CTRL%!5=BL%+2 1310 A%=2:R%=USR(&FFD1)

loop, close the rom file and end:
1320 NEXT
1330 CLOSE#SFILE
1340 UNTIL FALSE
1350 END

calculate the next free address in the rom; if it’s past the end reduce until it fits: 1360 DEF FNNXT(DONE%)
1370 LOCAL BASE%,FULL%
1380 BASE%=PTR#PHFILE+N%+20
1390 IF BASE% > &3FFE THEN = PTR#PHFILE
1400 FULL%=BASE%+L%+BLKS%*3-DONE%*259:IF BLKS%-DONE% > 1 THEN FULL%=FULL%+N%+20
1410 IF FULL% <= &3FFE THEN = FULL% ELSE = BASE%+((&3FFE - BASE%) DIV 259) * 259

close the rom file, first writing &2B at the end, and the end address in the header:
1420 DEF PROCCLOSE
1430 BPUT#PHFILE,&2B
1440 PTR#PHFILE=60:BPUT#PHFILE,FNREVBYTE(EXT#PHFILE AND &FF):BPUT#PHFILE,FNREVBYTE(EXT#PHFILE DIV &100)
1450 CLOSE#(PHFILE)
1460 ENDPROC

open the rom file and write the (minimal) rom header:
1470 DEF PROCOPEN
1480 LOCAL I%
1490 PHFILE = OPENOUT("Ph_"+STR$~(PHFN)+"N")
1500 BPUT#PHFILE,0:BPUT#PHFILE,0:BPUT#PHFILE,ASC(“("): BPUT#PHFILE,ASC("C"):BPUT#PHFILE,ASC(")")
1510 FOR I%=1TO48:BPUT#PHFILE,32:NEXT
1520 BPUT#PHFILE,0:BPUT#PHFILE,0:BPUT#PHFILE,0:BPUT#PHFILE,0: BPUT#PHFILE,0:BPUT#PHFILE,0:BPUT#PHFILE,0:BPUT#PHFILE,&FF:BPUT#PHFI LE,&FF:BPUT#PHFILE,2:BPUT#PHFILE,0
1530 ENDPROC

write the full file header:
1540 DEF PROCHEADER(LAST%,EMPTY%,BN%) 1550 LOCAL I%
1560 $BUFF%=SSFN$

1570 BUFF%?N%=0:BUFF%!(N%+1)=LA%:BUFF%!(N%+5)=EA%:BUFF%!(N%+9)=BN% 1580 IF LAST% THEN BUFF%!(N%+11)=L% - PTR#SFILE:BUFF%?(N%+13)=&80 ELSE BUFF%!(N%+11)=256:BUFF%?(N%+13)=0
1590 IF EMPTY% THEN BUFF%?(N%+13)=BUFF%?(N%+13) OR &40
1600 IF AT% AND 4 THEN BUFF%?(N%+13)=BUFF%?(N%+13) OR 1
1610 BUFF%!(N%+14)=NXT%:BUFF%!(N%+18)=FNCRC(N%+18)
1620 BPUT#PHFILE,&2A:FOR I%=0 TO N%+19:BPUT#PHFILE,BUFF%?I%:NEXT 1630 ENDPROC

write an empty file:
1640 DEF PROCTITLE(N$)
1650 SSFN$=LEFT$(N$,10):N%=LEN(SSFN$)
1660 LA%=0:EA%=0:AT%=0:L%=0
1665 IF PTR#PHFILE >= &3FFE-N%-20 THEN PROCCLOSE: PHFN=(PHFN+1)AND&FF:PROCOPEN
1670 NXT%=PTR#PHFILE+N%+21
1680 PROCHEADER(TRUE,TRUE,0)
1690 ENDPROC

call the machine code CRC routine:
1700 DEF FNCRC (A%)
1710 R%=USR(CRC)
1720 =!&81

call the machine code byte reverse: 1730 DEF FNREVBYTE (A%)
1740 R%=USR(REVERSE)
1750 =R% MOD 256

assemble the two machine code routines: 1760 DEF PROCCODE(BUFF%)
1770 DIM MC% 100
1780 FOR I=0 TO 2 STEP 2
1790 P% = MC%
1800 [OPTI
1810 .REVERSE STA &80
1820 ROL &80
1830 ROR A
1840 ROL &80
1850 ROR A
1860 ROL &80
1870 ROR A
1880 ROL &80
1890 ROR A
1900 ROL &80
1910 ROR A
1920 ROL &80
1930 ROR A
1940 ROL &80
1950 ROR A
1960 ROL &80
1970 ROR A
1980 RTS
1990 .CRC STA &80
2000 LDA #0
2010 STA &82

2020 STA &81
2030 TAY
2040 .NBYT LDA &81
2050 EOR BUFF%,Y
2060 STA &81
2070 LDX #8
2080 .LOOP LDA &81
2090 ROL A
2100 BCC B7Z
2110 LDA &81
2120 EOR #8
2130 STA &81
2140 LDA &82
2150 EOR #&10
2160 STA &82
2170 .B7Z ROL &82
2180 ROL &81
2190 DEX
2200 BNE LOOP
2210 INY
2220 CPY &80
2230 BNE NBYT
2240 RTS
2250 ]
2260 NEXT
2270 ENDPROC

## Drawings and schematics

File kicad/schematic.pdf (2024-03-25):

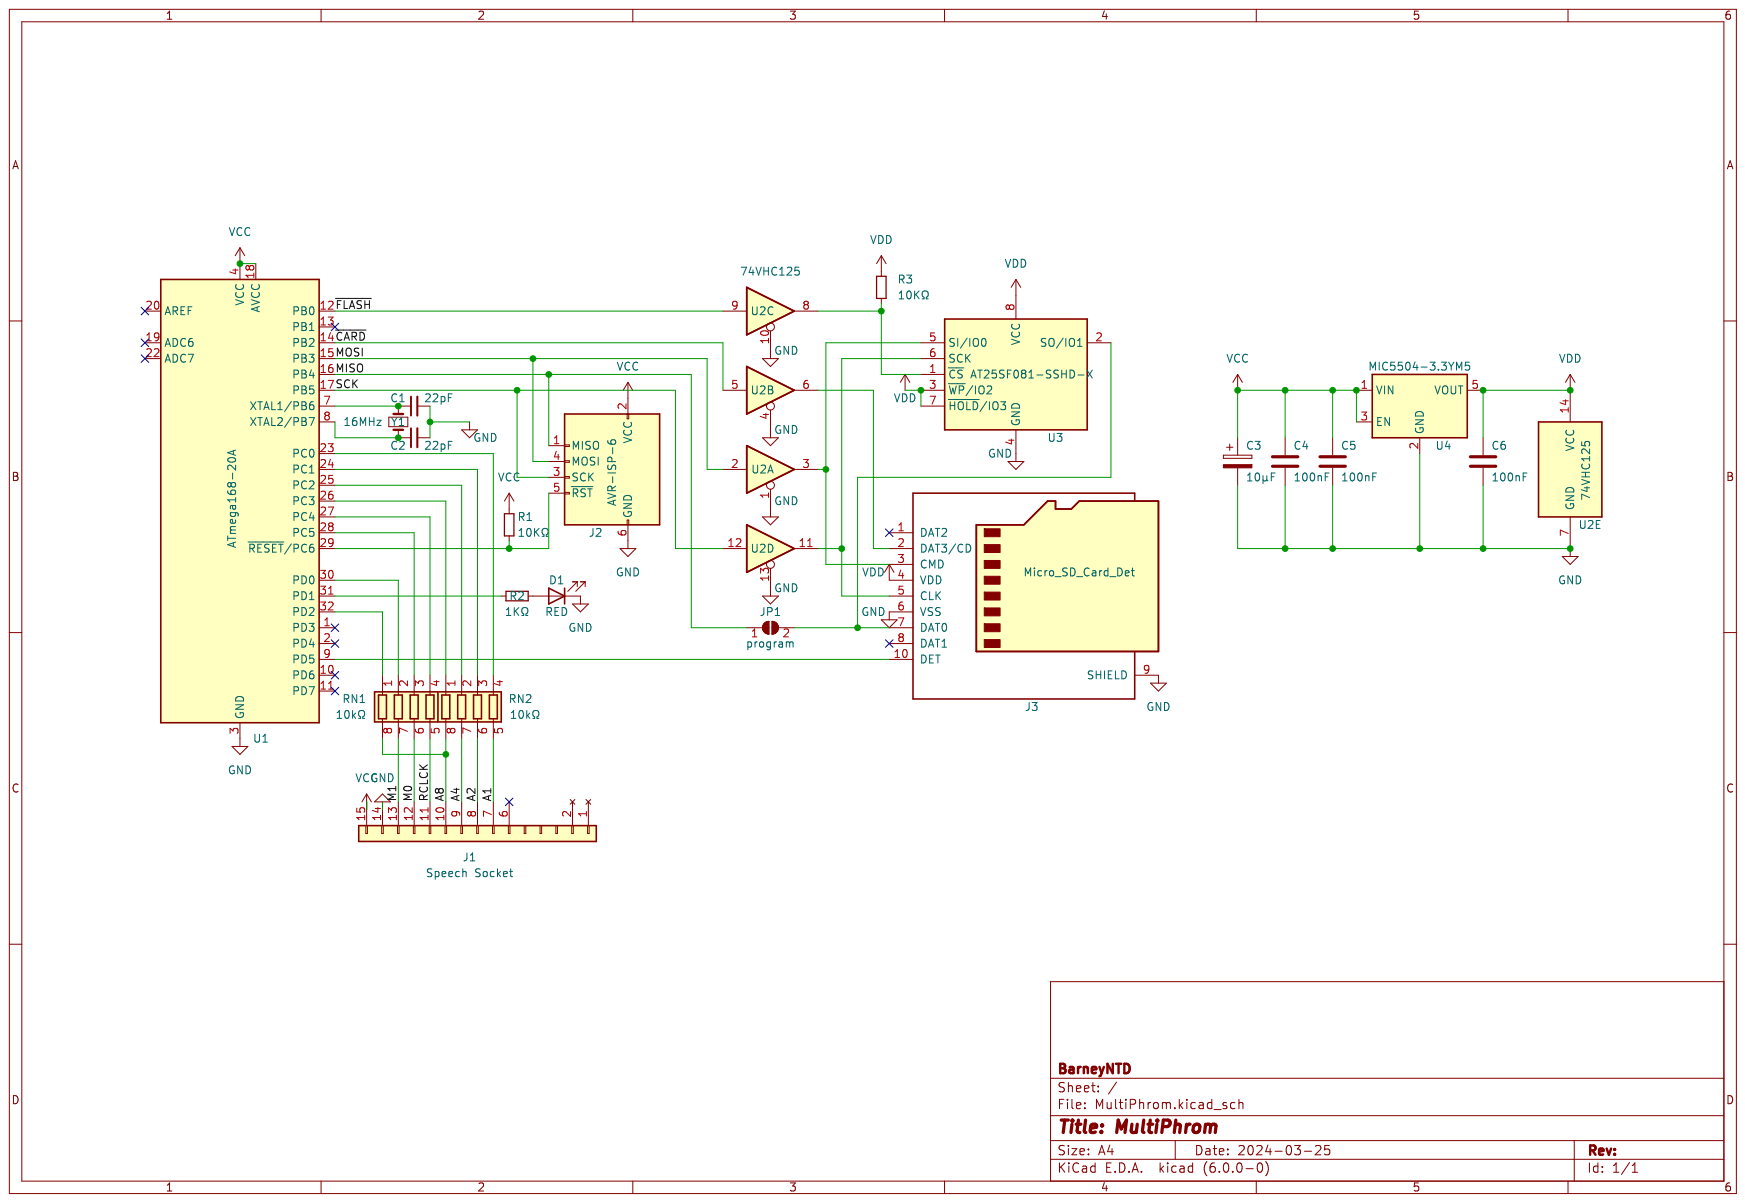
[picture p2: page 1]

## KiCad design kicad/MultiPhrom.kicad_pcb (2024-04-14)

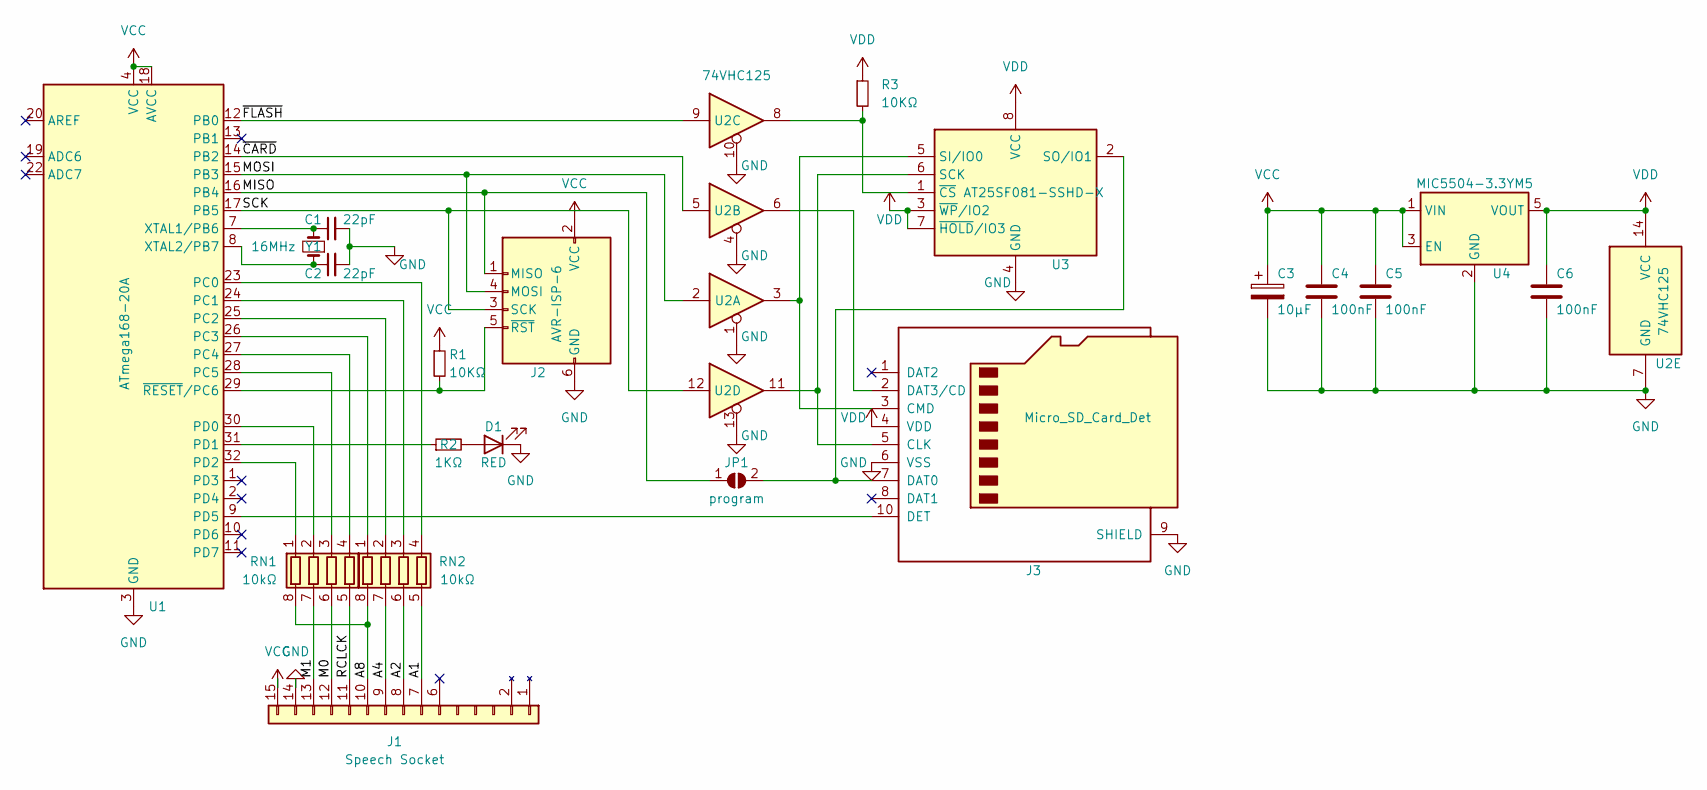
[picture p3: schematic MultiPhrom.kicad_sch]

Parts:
C1, C2: 22pF; C_1206_3216Metric_Pad1.33x1.80mm_HandSolder
C3: 10µF; CP_Radial_D5.0mm_P2.00mm
C4, C5, C6: 100nF; C_1206_3216Metric_Pad1.33x1.80mm_HandSolder
D1: RED; LED_1206_3216Metric_Pad1.42x1.75mm_HandSolder
J1: Speech Socket; BBC Speech Socket
J2: AVR-ISP-6; PinHeader_2x03_P2.54mm_Vertical
J3: Micro_SD_Card_Det; WR-CRD 693071010811
JP1: program; SolderJumper-2_P1.3mm_Open_RoundedPad1.0x1.5mm
R1, R3: 10KΩ; R_1206_3216Metric_Pad1.30x1.75mm_HandSolder
R2: 1KΩ; R_1206_3216Metric_Pad1.30x1.75mm_HandSolder
RN1, RN2: 10kΩ; R_Array_Convex_4x1206
U1: ATmega168-20A; TQFP-32_7x7mm_P0.8mm
U2: 74VHC125; SO-14_3.9x8.65mm_P1.27mm
U3: AT25SF081-SSHD-X; SOIC-8_3.9x4.9mm_P1.27mm
U4: MIC5504-3.3YM5; SOT-23-5
Y1: 16MHz; Crystal_HC49-4H_Vertical

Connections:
/A1: J1.7, RN2.5 (R4.2)
/A2: J1.8, RN2.6 (R3.2)
/A4: J1.9, RN2.7 (R2.2)
/A8: J1.10, RN1.8 (R1.2), RN2.8 (R1.2)
/M0: J1.12, RN1.6 (R3.2)
/M1: J1.13, RN1.7 (R2.2)
/MISO: J2.1 (MISO), JP1.1 (A), U1.16 (PB4)
/MOSI: J2.4 (MOSI), U1.15 (PB3), U2.2
/RCLCK: J1.11, RN1.5 (R4.2)
/SCK: J2.3 (SCK), U1.17 (PB5), U2.12
/~CARD: U1.14 (PB2), U2.5
/~FLASH: U1.12 (PB0), U2.9
GND: C1.2, C2.2, C3.2, C4.2, C5.2, C6.2, D1.1 (K), J1.14, J2.6 (GND), J3.6 (VSS), J3.9 (SHIELD), U1.3 (GND), U1.5 (GND), U1.21 (GND), U2.1, U2.4, U2.7 (GND), U2.10, U2.13, U3.4 (GND), U4.2 (GND)
unnamed: C1.1, U1.7 (XTAL1/PB6), Y1.2
unnamed: C2.1, U1.8 (XTAL2/PB7), Y1.1
unnamed: D1.2 (A), R2.2
unnamed: J2.5 (~RST), R1.2, U1.29 (~RESET/PC6)
unnamed: J3.2 (DAT3/CD), U2.6
unnamed: J3.3 (CMD), U2.3, U3.5 (SI/IO0)
unnamed: J3.5 (CLK), U2.11, U3.6 (SCK)
unnamed: J3.7 (DAT0), JP1.2 (B), U3.2 (SO/IO1)
unnamed: J3.10 (DET), U1.9 (PD5)
unnamed: R2.1, U1.31 (PD1)
unnamed: R3.2, U2.8, U3.1 (~CS)
unnamed: RN1.1 (R1.1), U1.32 (PD2)
unnamed: RN1.2 (R2.1), U1.30 (PD0)
unnamed: RN1.3 (R3.1), U1.28 (PC5)
unnamed: RN1.4 (R4.1), U1.27 (PC4)
unnamed: RN2.1 (R1.1), U1.26 (PC3)
unnamed: RN2.2 (R2.1), U1.25 (PC2)
unnamed: RN2.3 (R3.1), U1.24 (PC1)
unnamed: RN2.4 (R4.1), U1.23 (PC0)
VCC: C3.1, C4.1, C5.1, J1.15, J2.2 (VCC), R1.1, U1.4 (VCC), U1.6 (VCC), U1.18 (AVCC), U4.1 (VIN), U4.3 (EN)
VDD: C6.1, J3.4 (VDD), R3.1, U2.14 (VCC), U3.3 (~WP/IO2), U3.7 (~HOLD/IO3), U3.8 (VCC), U4.5 (VOUT)

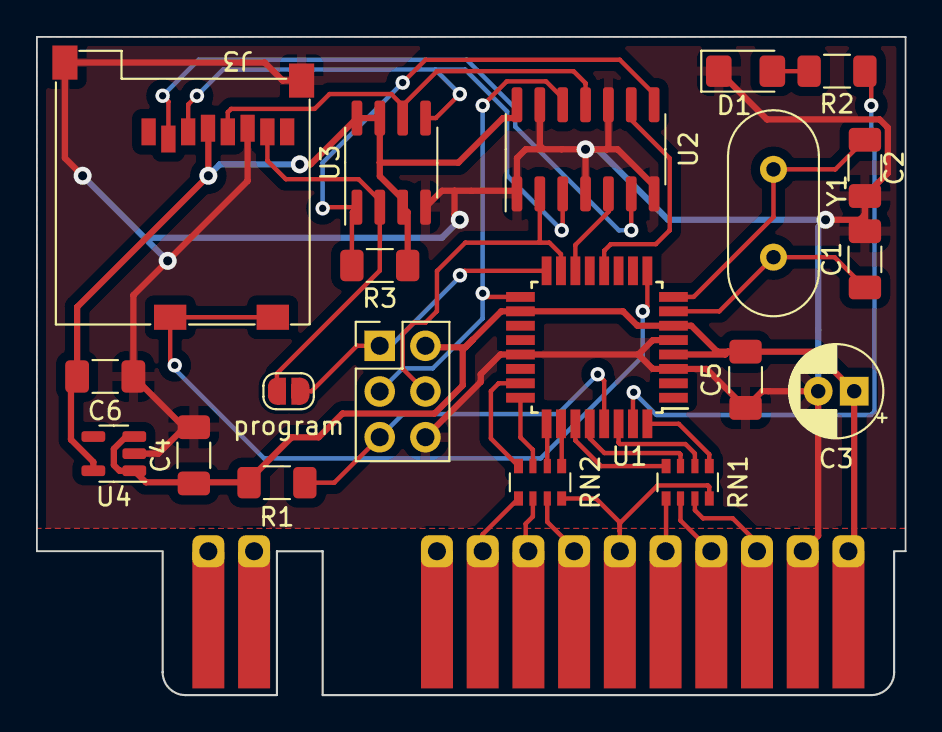
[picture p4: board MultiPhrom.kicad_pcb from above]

Board: 2 copper layers, 48.3 x 36.6 mm, 21 parts (0 on the bottom side), 34 nets.

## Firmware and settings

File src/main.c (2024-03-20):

//
//  main.c
//  MultiPhrom
//
//  Created by Barney Hilken on 20/03/2020.
//  Copyright © 2020-2024 Barney Hilken. This file is free for noncommercial use: see licence for details.
//



#include "hardwaremap.h"
#include "flashrom.h"
#include "sdcard.h"
#include <avr/interrupt.h>
#include <avr/wdt.h>
#include <util/atomic.h>


//  interrupt to detect SD card

ISR(DTCT_INT_vect)
{
    // if card inserted, restart
    if (DTCT)
    {
        wdt_enable(WDTO_30MS);
        while(TRUE);
    }
}

void setupCardDetect (void)
{
    ATOMIC_BLOCK (ATOMIC_FORCEON)
    {
        DTCT_INT_enable;
    }
}


uint8_t ignoreSlot[16];

void read_rom_data (uint32_t address)
{
    uint8_t emulating = !ignoreSlot[(address >> 14) & 0xF];
    
    // wait for dummy read command, exit on address command
    while (!M0)
        if (M1) goto exit;
    while (M0)
        if (M1) goto exit;

    // set read address
    flashReadAddress(address);
    
	// wait for actual read command, exit on address command
	while (!M0)
		if (M1) goto exit;

    // if emulating this rom, take control of DATA/ADDB
    if (emulating)
    	SET_DATA_OUTPUT;

    uint8_t byte;
    while (TRUE)
    {
        // get the next byte of flash data
        byte = flashReadByte ();
        
        for (uint8_t bitcount = 0; bitcount < 8; bitcount++)
        {
			uint8_t databit = ((byte & 0x80) != 0);
			byte <<= 1;
			
			// wait for end of read command, exit on address command
			while (M0)
				if (M1) goto exit;

            // if emulating this rom, set DATA/ADDB according to the data bit
            if (emulating)
                SET_DATA(databit);

            // wait for start of next read command, exit on address command
            while (!M0)
                if (M1) goto exit;
            
            // if emulating this rom, check DATA/ADDB for conflict
            if (emulating && ADD8 != databit)
			{
				SET_DATA_INPUT;
				SET_DATA(0);
				ignoreSlot[(address >> 14) & 0xF] = TRUE;
				emulating = FALSE;
			}
        }

        // increment address
        address = (address + 1) & 0xFFFFF;
        
        // if moving to a new slot, check whether to emulate
        if ((address & 0x3FFF) == 0)
        {
            emulating = !ignoreSlot[address >> 14];
            if (emulating)
            {
                SET_DATA_OUTPUT;
            }
            else
            {
                SET_DATA_INPUT;
                SET_DATA(0);
            }
        }
    }

exit:
    // end read byte sequence
    flashEndRead ();
    
    // set DATA back to input
    SET_DATA_INPUT;
    SET_DATA(0);
}

int main (void)
{
    // turn off unused MCU features
    UNUSED_OFF;
    MCUSR = 0;
    wdt_disable();
    
    // Set all speech rom pins to input and turn off weak pull-ups
    SET_M0_INPUT;
    SET_M0_NOPULLUP;

    SET_M1_INPUT;
    SET_M1_NOPULLUP;

    SET_CLK_INPUT;
    SET_CLK_NOPULLUP;

    SET_ADD_INPUT;
    SET_ADD_NOPULLUP;
    
    SET_DATA_INPUT;
    SET_DATA(0);
    
    //  set SPI pins correctly
    SET_MISO_INPUT;
    SET_MISO_NOPULLUP;

    SET_MOSI_OUTPUT;
    SET_SCK_OUTPUT;
    
    // deselect flash chip & SD card
    SET_CHIP_OUTPUT;
    SET_CHIP(1);

    SET_CARD_OUTPUT;
    SET_CARD(1);
    
    // set other pins
    SET_DTCT_INPUT;
    SET_DTCT_PULLUP;
    SET_LED_OUTPUT;
    SET_LED(0);

    if (DTCT)
        readSDCard ();
    
    flashSetupSPI ();
    setupCardDetect();
    
    while (TRUE)
    {
        // load new address
        uint32_t address;
    loop: address = 0;
        for (uint8_t shift = 0; shift < 20; shift += 4)
        {
            // wait for start of address command
            while (!M1)
                if (M0) goto loop;

            // wait for clock
            while (CLK);

            // read nibble
            address |= (uint32_t)ADD << shift;

            //wait for end of address command
            while (M1)
                if (M0) goto loop;
        }
        
        // read the data, as requested
        read_rom_data (address);
    }
}

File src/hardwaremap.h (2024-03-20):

//
//  hardwaremap.h
//  MultiPhrom
//
//  Created by Barney Hilken on 20/03/2020.
//  Copyright © 2020 Barney Hilken. This file is free for noncommercial use: see licence for details.
//


#ifndef HARDWAREMAP_H_
#define HARDWAREMAP_H_

// Global includes
#include <avr/io.h>

// Some useful definitions
#define FALSE	0
#define TRUE	1
#define NULL    0


// TMS6100 IO Pins

// M0 (PC5)
#define M0_BITMASK          (1 << 5)
#define SET_M0_INPUT        DDRC &= ~M0_BITMASK
#define SET_M0_NOPULLUP     PORTC &= ~M0_BITMASK
#define M0                  ((PINC & M0_BITMASK) != 0)

// M1 (PD0)
#define M1_BITMASK          (1 << 0)
#define SET_M1_INPUT        DDRD &= ~M1_BITMASK
#define SET_M1_NOPULLUP     PORTD &= ~M1_BITMASK
#define M1                  ((PIND & M1_BITMASK) != 0)

// ROMCLK (PC4)
#define CLK_BITMASK         (1 << 4)
#define SET_CLK_INPUT       DDRC &= ~CLK_BITMASK
#define SET_CLK_NOPULLUP    PORTC &= ~CLK_BITMASK
#define CLK                 ((PINC & CLK_BITMASK) != 0)

// ADD (PC0-3)
#define ADD1_BIT            0
#define ADD_BITMASK         (0x0F << ADD1_BIT)
#define SET_ADD_INPUT       DDRC &= ~ADD_BITMASK
#define SET_ADD_NOPULLUP    PORTC &= ~ADD_BITMASK
#define ADD                 ((PINC & ADD_BITMASK) >> ADD1_BIT)

// ADD8 (ADD >> 3)
#define ADD8_BITMASK        (1 << (ADD1_BIT + 3))
#define ADD8                ((PINC & ADD8_BITMASK) != 0)

// DATA (PD2), connected to ADD8 via resistor
#define DATA_BITMASK        (1 << 2)
#define SET_DATA_INPUT      DDRD &= ~DATA_BITMASK
#define SET_DATA_OUTPUT     DDRD |= DATA_BITMASK
#define SET_DATA(b)         PORTD = (PORTD & ~DATA_BITMASK) | ((b) ? DATA_BITMASK : 0)

// SPI interface

// MISO (PB4)
#define MISO_BITMASK        (1 << 4)
#define SET_MISO_INPUT      DDRB &= ~MISO_BITMASK
#define SET_MISO_NOPULLUP   PORTB &= ~MISO_BITMASK
#define MISO                ((PINB & MISO_BITMASK) != 0)

// MOSI (PB3)
#define MOSI_BIT            3
#define MOSI_BITMASK        (1 << MOSI_BIT)
#define SET_MOSI_OUTPUT     DDRB |= MOSI_BITMASK
#define SET_MOSI(b)         PORTB = (PORTB & ~MOSI_BITMASK) | ((b) ? MOSI_BITMASK : 0)

// SCK (PB5)
#define SCK_BIT             5
#define SCK_BITMASK         (1 << SCK_BIT)
#define SET_SCK_OUTPUT      DDRB |= SCK_BITMASK
#define SET_SCK(b)          PORTB = (PORTB & ~SCK_BITMASK) | ((b) ? SCK_BITMASK : 0)

// CHIP (PB0)
#define CHIP_BIT            0
#define CHIP_BITMASK        (1 << CHIP_BIT)
#define SET_CHIP_OUTPUT     DDRB |= CHIP_BITMASK
#define SET_CHIP(b)         PORTB = (PORTB & ~CHIP_BITMASK) | ((b) ? CHIP_BITMASK : 0)

// CARD (PB2)
#define CARD_BIT            2
#define CARD_BITMASK        (1 << CARD_BIT)
#define SET_CARD_OUTPUT     DDRB |= CARD_BITMASK
#define SET_CARD(b)         PORTB = (PORTB & ~CARD_BITMASK) | ((b) ? CARD_BITMASK : 0)

// Other IO pins

// LED (PD1)
#define LED_BIT             1
#define LED_BITMASK         (1 << LED_BIT)
#define SET_LED_OUTPUT      DDRD |= LED_BITMASK
#define SET_LED(b)          PORTD = (PORTD & ~LED_BITMASK) | ((b) ? LED_BITMASK : 0)

// DTCT (PD5)
#define DTCT_BITMASK        (1 << 5)
#define SET_DTCT_INPUT      DDRD &= ~DTCT_BITMASK
#define SET_DTCT_PULLUP     PORTD |= DTCT_BITMASK
#define DTCT                ((PIND & DTCT_BITMASK) != 0)
#define DTCT_INT_vect       PCINT2_vect
#define DTCT_INT_enable     PCMSK2 |= (1 << PCINT21); PCICR |= (1 << PCIE2)



// turn off unused features
#define UNUSED_OFF          PRR = (1 << PRADC) | (1 << PRUSART0) | (1 << PRTIM1) | (1 << PRTIM0) | (1 << PRTIM2) | (1 << PRTWI)

#endif /* HARDWAREMAP_H_ */

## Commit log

2024-03-20 Initial git commit
    [MultiPhrom.kicad_pcb, MultiPhrom.kicad_sch]
2024-03-25 more examples
    [MultiPhrom.kicad_sch]
2024-04-14 Add sample phroms
    [MultiPhrom.kicad_pcb]
